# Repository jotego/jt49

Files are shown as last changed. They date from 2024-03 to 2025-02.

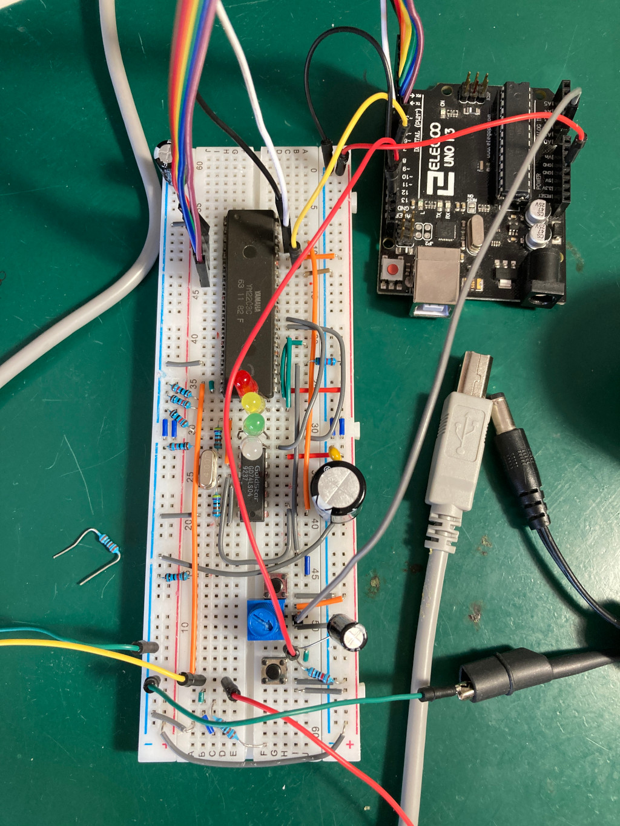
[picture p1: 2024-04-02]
lab/ym2203/ym2203_setup.jpeg

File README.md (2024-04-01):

# JT49 FPGA Clone of YM2149 hardware by Jose Tejada (@topapate)

You can show your appreciation through

* [Patreon](https://patreon.com/jotego), by supporting open source retro releases

YM2149 compatible Verilog core, with emphasis on FPGA implementation as part of JT12 in order to recreate the YM2203 part.

## Documentation

- [AY-3-8910 Data Manual](https://archive.org/details/AY-3-8910-8912_Feb-1979/page/n51/mode/2up)
- [AY-3-8919 Reverse Engineered](https://github.com/lvd2/ay-3-8910_reverse_engineered)
- [YM2149](https://archive.org/details/bitsavers_yamahaYM21_3070829)

## Using JT49 in a git project

If you are using JT49 in a git project, the best way to add it to your project is:

1. Optionally fork JT49's repository to your own GitHub account
2. Add it as a submodule to your git project: `git submodule add https://github.com/jotego/jt49.git`
3. Now you can refer to the RTL files in **jt49/hdl**

The advantages of a using a git submodule are:

1. Your project contains a reference to a commit of the JT49 repository
2. As long as you do not manually update the JT49 submodule, it will keep pointing to the same commit
3. Each time you make a commit in your project, it will include a pointer to the JT49 commit used. So you will always know the JT49 that worked for you
4. If JT49 is updated and you want to get the changes, simply update the submodule using git. The new JT49 commit used will be annotated in your project's next commit. So the history of your project will reflect that change too.
5. JT49 files will be intact and you will use the files without altering them.

## Usage

There are two top level files you can use:
 - **jt49_bus**: presents the expected AY-3-8910 interface
 - **jt49**: presents a simplified interface, ideal to embed. This is the one used by jt12

clk_en cannot be set to 1 for correct operation. The design assumes that there will be at least one empty clock cycle between every two clk_en high clock cycles.
 
## Files for Simulation and Synthesis

When used inside a [JTFRAME](https://github.com/jotego/jtframe) project, you can use the [yaml](hdl/jt49.yaml) file provided. If you are using this repository on its own, there is a [qip](syn/quartus/jt49.qip) for Intel Quartus available.

It is recommended to use this repository as a [git submodule](https://git-scm.com/book/en/v2/Git-Tools-Submodules) in your project.

## Port Description jt49

Name     | Direction | Width | Purpose
---------|-----------|-------|-------------------------------------
rst_n    | input     |       | active-low asynchronous reset signal
clk      | input     |       | clock
clk_en   | input     |       | clock enable. It cannot be a permanent 1
addr     | input     | 4     | selects the register to access to
cs_n     | input     |       | chip-select, active low
wr_n     | input     |       | active-low write signal
din      | input     | 8     | data to write to registers
sel      | input     |       | input clock is further divided by 2 when low
dout     | output    | 8     | data read from registers. Updated when cs_n is low
sound    | output    | 10    | Unsigned combined output of the three channels    
A        | output    | 8     | Unsigned output of channel A
B        | output    | 8     | Unsigned output of channel B
C        | output    | 8     | Unsigned output of channel C 

The module is not designed to be used at full clk speed. The clock enable input signal should divide the clock at least by two. This is needed because the volume LUT is shared for all three channels and the pipeline does not include wait states for the LUT as wait states happen naturally when clk_en is used.

The ports of **jt49_bus** replace the CPU interface with that of the original AY-3-8910.

Name     | Direction | Width | Purpose
---------|-----------|-------|-------------------------------------
rst_n    | input     |       | active-low asynchronous reset signal
clk      | input     |       | clock
clk_en   | input     |       | clock enable. It cannot be a permanent 1
bdir     | input     |       | bdir pin of AY-3-8910            
bc1      | input     |       | bc1  pin of AY-3-8910
din      | input     | 8     | data to write to registers
sel      | input     |       | input clock is further divided by 2 when low
dout     | output    | 8     | data read from registers. Updated when cs_n is low
sound    | output    | 10    | Unsigned combined output of the three channels    
A        | output    | 8     | Unsigned output of channel A
B        | output    | 8     | Unsigned output of channel B
C        | output    | 8     | Unsigned output of channel C
IOA_in   | input     | 8     | I/O port A, input side
IOA_in   | output    | 8     | I/O port A, output side
IOB_in   | input     | 8     | I/O port B, input side
IOB_in   | output    | 8     | I/O port B, output side

## Comparison with AY-3-8910 Verilog Model

A simulation test bench of jt49 vs the AY-3-8910 model (available in the doc folder via a git submodule) is available in folder ver/comp. The simulation uses a simple text file to enter arbitrary commands (test_cmd). The command file is converted to hexadecimal by parser.awk and used in simulation. The following parameters were tested:

Item                 |  Compliance      | Remarks
---------------------|------------------|-------------------------------
channel period       |  Yes             | Tested: 0, 1 and FFFF values
noise period         |  Yes             | Tested: 0, 7 and 1F values
envelope shape       |  Yes             | Tested all 16 shapes
envelope period      |  Yes             | Tested 0 and FFF values

## Resistor Load Modelling

The YM2149 was used to measure the output circuitry. According to AY-3-8910 schematics, there are 16 NMOS devices for each channel. Depending on the amplitude settings, only one of them will be active. These numbers render values that agree with the datasheet and measurements:

- Rload = 1 kOhm
- Smallest Ron = 900 Ohm (for level=15)
- Largest Roff = 3 MOhm (for level=0)
- Scale factor from one MOS to the next = 1.55

Each output level is the combination of one MOS being on and the rest off, so they combine into a single impedance, which then forms a resistor divider with the load.

The output MOS will hold its impedance even if an extra 1V is added at the load resistor (reducing the MOS headroom)

## Non Linear Effects

- Channel mixing effects by short circuiting the outputs in AY-3-8910 are not modelled
- Non linearity in YM2203 when shorting all outputs is modeled via parameter YM2203_LUMPED

Non linear effects depend on the way the chip is connected and its model. See [the connection list](doc/conn.md).

## Related Projects

Other sound chips from the same author

Chip                   | Repository
-----------------------|------------
YM2203, YM2612, YM2610 | [JT12](https://github.com/jotego/jt12)
YM2151                 | [JT51](https://github.com/jotego/jt51)
YM3526                 | [JTOPL](https://github.com/jotego/jtopl)
YM2149                 | [JT49](https://github.com/jotego/jt49)
sn76489an              | [JT89](https://github.com/jotego/jt89)
OKI 6295               | [JT6295](https://github.com/jotego/jt6295)
OKI MSM5205            | [JT5205](https://github.com/jotego/jt5205)
NEC uPN7759            | [JT7759](https://github.com/jotego/jt7759)

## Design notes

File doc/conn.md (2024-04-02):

# Connectivity Cases

Definitions:

- **Per channel**: resistor from channel output to ground (kOhm)
- **Join res**: resistors joining from ch. output to a net common to all channels (kOhm)
- **Lump res**: resistor from the common net to ground (kOhm)
- **ac**: ac coupling capacitor, in uF

Game                    | Chip Model      | Per ch. | Join R. | Lump  | ac  | Remarks
------------------------|-----------------|---------|---------|-------|-----|----------
Ghosts'n Goblins        | YM2203          |  1      |   4.7   | 2     | 10  |
Robocop                 | YM2203          |  10     |  56     | 1     | 10  |
Combat School           | YM2203          |         | 3.2     | 1     |  4.7| one ac cap for all channels
Bubble Bobble           | YM2203          |         | shorted | 1     | 10  | single cap for all chips
The New Zealand Story   | YM2203          |         | shorted | 1     | 0.1 | Applies to other boards of the same series (JTKIWI core)
1942                    | AY-3-8910       | 10      | 220     | 2     | 10  |
Karate Champ            | AY-3-8910       |  1      |         | 1     |  1  | ch. C of chip 1A
Karate Champ            | AY-3-8910       |         | shorted | 1     |  1  | ch. B/C of chip 1A, all of chip 3A (5 ch.)
Roc'n Rope              | AY-3-8910       | 6.1     |         |       |  1  | all ch. connected to a virtual ground

Bubble Bobble is misconnected. Due to YM2203's buffered output, shorting all channels will make the higher output voltage dominate at any time.

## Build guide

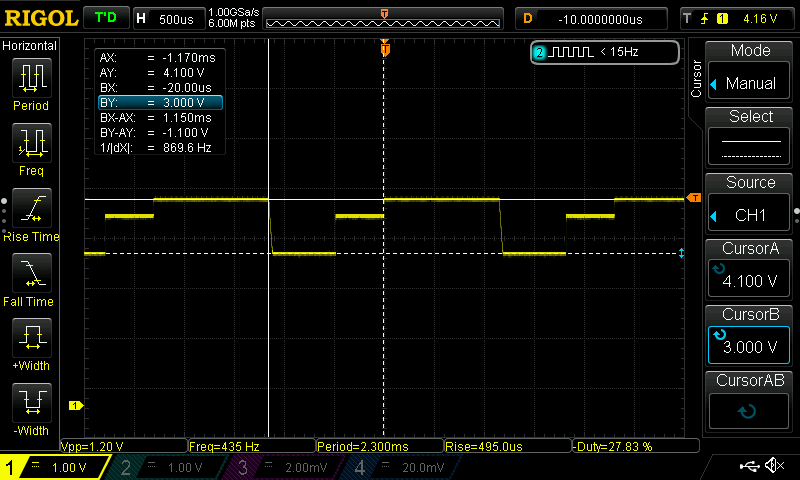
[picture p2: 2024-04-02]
lab/ym2203/DS1Z_QuickPrint20.png

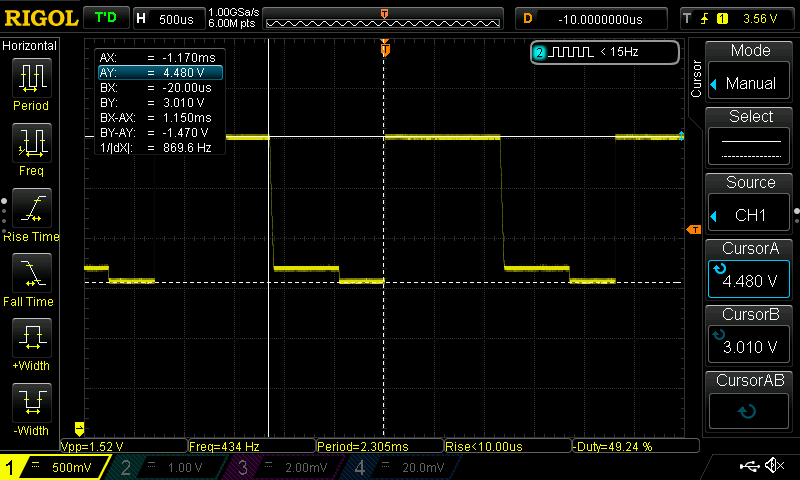
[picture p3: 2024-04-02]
lab/ym2203/DS1Z_QuickPrint23.png

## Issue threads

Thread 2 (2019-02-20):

Noise generator pitch too high?

jotego, 2019-02-20:

jotego, 2019-10-03:
Fixed.

Closed 2019-10-03.

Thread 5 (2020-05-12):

missing parameters

LMN128, 2020-05-12:
Hi, I have notice, there are missing parameters if i want use it with current jt12 commint.
There is:
`jt49 #(.COMP(2'b01), .CLKDIV(2)) `
in jt12_top
It looks like there is old version jt49 maybe.
Thanks a lot.

LMN128, 2020-05-13:
sorry for the confusion. I have used different git repo https://github.com/sorgelig/jt49. it's not fresh.

Closed 2020-05-13.

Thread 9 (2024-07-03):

check behavior with period=0

jotego, 2024-07-03:
Check with the model or Arduino setup whether there is output or not when the period is set to zero.

jotego, 2024-12-08:
The FairyLand Story expects no sound when period is set to zero. Otherwise, there is noise after jumping.

Closed 2024-12-08.

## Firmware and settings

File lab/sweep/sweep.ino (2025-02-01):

/*

pin connections

Arduino   | YM2203  | Use
----------|---------|-----
  2       |   40    | D0
  3       |    2    | D1
  4       |    3    | D2
  5       |    4    | D3
  6       |    5    | D4
  7       |    6    | D5
  8       |    7    | D6
  9       |   38    | phi M
 10       |    8    | D7
 11       |   37    | A0
 12       |   35    | /WR
 13       |   24    | /IC (reset)
 A0       |   20    | resistor (channel A)

Other YM2203 pins

YM2203 | Connection
-------|--------------
 1     | GND (ground)
9-16   | NC
 17    | GND
 18-19 | NC/short to 20 (channels B, C)
 39    | NC
 36    | VCC (/RD)
 34    | GND (/CS)R_US
 25-33 | NC
 22-23 | NC
 21    | VCC (supply)

Measure:

Run the program for each of these configurations:

 1. Connect channel A to  1  kOhm, leave channels B,C disconnected
 2. Connect channel A to 10 kOhm,  leave channels B,C disconnected
 3. Join channels A,B,C to the same  1 kOhm resistor
 4. Join channels A,B,C to the same 10 kOhm resistor

*/

const int A0PIN=8, WRPIN=9, ICPIN=10;

void setup() {
	// Set Pins 2-12 as an output
	DDRD=0xff;
	DDRB=0xff;
	// pinMode(A0PIN, OUTPUT);
	// pinMode(WRPIN, OUTPUT);
	// pinMode(ICPIN, OUTPUT);
	// PSG
	psg_setup();
	// Serial.begin(9600);
}

void wrDout(int v) {
	PORTD=v&0xff;
	PORTB=PINB&0xfd; // WR low
	PORTB=PINB|0x02; // WR high
}

void wrReg( int r, int v) {
	PORTB=0xfe; // A0 low
	wrDout(r);
	PORTB=0xff; // A0 hihg
	wrDout(v);
}

void psg_setup() {
	// reset
	digitalWrite(ICPIN,0);
	delay(100);
	digitalWrite(ICPIN,1);
	delay(100);

	for(int k=0;k<6;k+=2) { // set minimum freq for all channels
		wrReg(0+k,0xff);
		wrReg(1+k,0x0);
	}
	wrReg(7, 7<<3 ); // tone enable
	wrReg(11, 0 );   // fast envelope
	wrReg(12, 0 );
	wrReg(13, 13 ); // envelope held high
}

// void loop() {
// 	for(int k=0;;k++) PORTD=k&0xff;
// }

void loop() {
	psg_setup();
	int vol[3]={0,0,0};
	char str[64];
	for(int ch=0;ch<3;ch++) {
		for(int k=0;k<16;k++) {
			vol[ch]=k;
			wrReg( 8,vol[0]);
			wrReg( 9,vol[1]);
			wrReg(10,vol[2]);
			delay(50);
			int amp = analogRead(A0);
			sprintf(str,"%d,%d,%d,%04d",vol[0],vol[1],vol[2],amp);
			// Serial.println(str);
		}
	}
}

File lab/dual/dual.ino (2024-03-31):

// Drives two channels with overlapping amplitudes

const int A0PIN=8,  // PB0
          WRPIN=9,  // PB1
          ICPIN=10; // PB2

void setup() {
	// Set ports B and D as an output
	DDRD=0xff;
	DDRB=0x07;
	// PSG
	psg_setup();
}

void wrDout(int v, int a0 ) {
	PORTD=v;
	a0=(a0&1)|4;	// keep IC high (bit 2)
	PORTB=a0; // WR low
	PORTB=a0|0x02; // WR high
	// delay(1);
}

void wrReg( int r, int v) {
	wrDout(r,0);
	wrDout(v,1);
}

void psg_setup() {
	// reset - if not c
	digitalWrite(ICPIN,0);
	delay(100);
	digitalWrite(ICPIN,1);
	delay(100);

	wrReg(1,0xf);
	wrReg(0,0x80);
	wrReg(3,0xf);
	wrReg(5,0x80);
	wrReg(2,0xf);
	wrReg(4,0x80);

	// wrReg(0x2d,0); // pre scaler 658 kHz
	// wrReg(0x2e,0);    // pre scaler 1.3 MHz
	wrReg(0x21,0); 		// no test
	wrReg(0x2f,0);    	// pre scaler 2.0 MHz, SSG=full clock
	wrReg(7, 0370 ); 	// tone enabled, IO ports as outputs
	wrReg(6, 0x1f ); 	// noise

	for(int k=010; k<013;k++ ) wrReg( k, 15 );
	wrReg(011,13);
	delay(11);
}

int edge() {
	static int last=0;
	int b = (PINB>>5)&1;
	int edge = b && !last;
	last = b;
	return edge;
}

void loop() {
	static unsigned old=0, volB=0;
	unsigned amp = analogRead(A0)>>2;
	// if( edge() ) volB += 4;
	// 	// volB = volB==15 ? 0 : (volB<<1)|1;
	// wrReg( 011, volB ); // volume channel B
	// wrReg( 0xf, volB ); // show on YM2203's port B	
	if( old!= amp ) wrReg(2,0x80|(amp>>3));
	old=amp;
	delay(20);
}

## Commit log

2019-01-15 Started work on DC removal filter
2019-01-16 DC removal filter added
2019-11-06 fixed appearance of several regs and wires so that they are defined before they are used. This caused compilation errors in some simulators, for example modelsim
2020-05-16 Added support button on github
2020-11-25 sample output added
2023-11-04 Removed submodule with schematics to make the repository lighter
2024-03-14 sweep measurement on Arduino
2024-03-16 PSG output visible. AGND (pin 17) was not connected
2024-03-22 doc, minor
    [lab.ods]
2024-03-31 Measured YM2203 output voltage for different loads (two chips)
    [lab.ods]
2024-03-31 lab: 2 channels shorted
    [lab.ods]
2024-03-31 more measurements
    [lab.ods]
2024-04-01 YM2203_LUMPED parameter to model the non linear effect in YM2203
    [lab.ods]
2025-02-01 arduino test bench sch -wip-
    [arduino.kicad_pcb, arduino.kicad_sch]
